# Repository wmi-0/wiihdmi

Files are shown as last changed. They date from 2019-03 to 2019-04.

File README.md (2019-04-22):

# wiihdmi
HDMI for your Wii powered by GCVideo

This PCB is based on the popular GCVideo project as well as the Shuriken V3 schematics and features HDMI output (240p, 480i, 480p) for the Wii.
Menu navigation is possible via IR-remote or Gamecube controller.  
One of the main goals for this project was to keep it as cheap as possible.
This means no flex-cable for an easier install, no replacement of analog output (RGB/Component) and most importantly a 2-layer PCB design for cheap manufacturing.

**Consider this project as a beta for now.**  
I've spent several hours testing it on my launch-model Wii, but I'd like to hear some second opinions calling it ready for general use.

## Compatibility
### main_pcb_6_layer
Confirmed to work on RVL-CPU-01 boards.  
The layout possibly fits RVL-CPU-20 as well, but this is currently untested. Won't (properly) fit RVL-CPU-30.  

### main_pcb_4_layer
The new PCB layout is designed for 4-layer Wiis (RVL-CPU-40/50/60) but it's untested as of now.

Both designs use a 2-layer PCB layout which can be manufactured on the cheap, 4/6-layer is just the number of layers used on the intended target Wii mainboard.

## Install
See [GCVideo documentation](https://github.com/ikorb/gcvideo/blob/master/HDL/gcvideo_dvi/README-Wii.md#digital-audio-and-video)

## BOM
### Main PCB
| Designator  | Component |
| --- | --- |
| U1  | XC3S200A-4VQG100C  |
| U2  | M25P40  |
| U3  | TPS74012DGKR  |
| U4  | IRM-V538/TR1  |
| SW1  | EVQ9P701P  |
| J3  | 15 pin FFC connector 0.5mm pin pitch  |
| C1, C2  | 1 uF, 0805  |
| C3  | 10 uF, 0805  |
| C4-C12  | 0.1 uF, 0805  |
| R1, R3  | 4.7K, 0805  |
| R2  | 330, 0805  |

Use 0603 components for main_pcb_4_layer.

### HDMI PCB
| Designator  | Component |
| --- | --- |
| J1  | 15 pin FFC connector 0.5mm pin pitch  |
| J2  | Mini-HDMI (Type C) socket  |
| R1  | 180, 0402  |
| R2, R3  | 10K, 0402  |
| U1-U3  | TPD4S010 DQA (optional)  |

Use 0.8mm PCB thickness for both PCBs.

## Todos and next steps
- ~~PCB for 4-layer, 65nm Wii consoles (RVL-CPU-40+)~~
- ~~Provide better install pictures showing the current version of the PCB~~
- Switch to a more common 16 pin FFC instead of 15 pin
- Possibly add half-cut vias as anchor points (the initial design already had some, but the PCB manufacturer charged extra so I removed them again)
- KiCad project cleanup

## Acknowledgements
[ikorb](https://github.com/ikorb): GCVideo project  
[Steven Taffs](http://www.retro-system.com/shuriken%20video.htm): Shuriken V3 schematic and incredibly useful M25P40 programming tool  
[citrus3000psi](https://github.com/citrus3000psi): Inspiration from GCHDMI designs

## License
This project is licensed under the GPL v3.0 License - see the LICENSE.md file for details

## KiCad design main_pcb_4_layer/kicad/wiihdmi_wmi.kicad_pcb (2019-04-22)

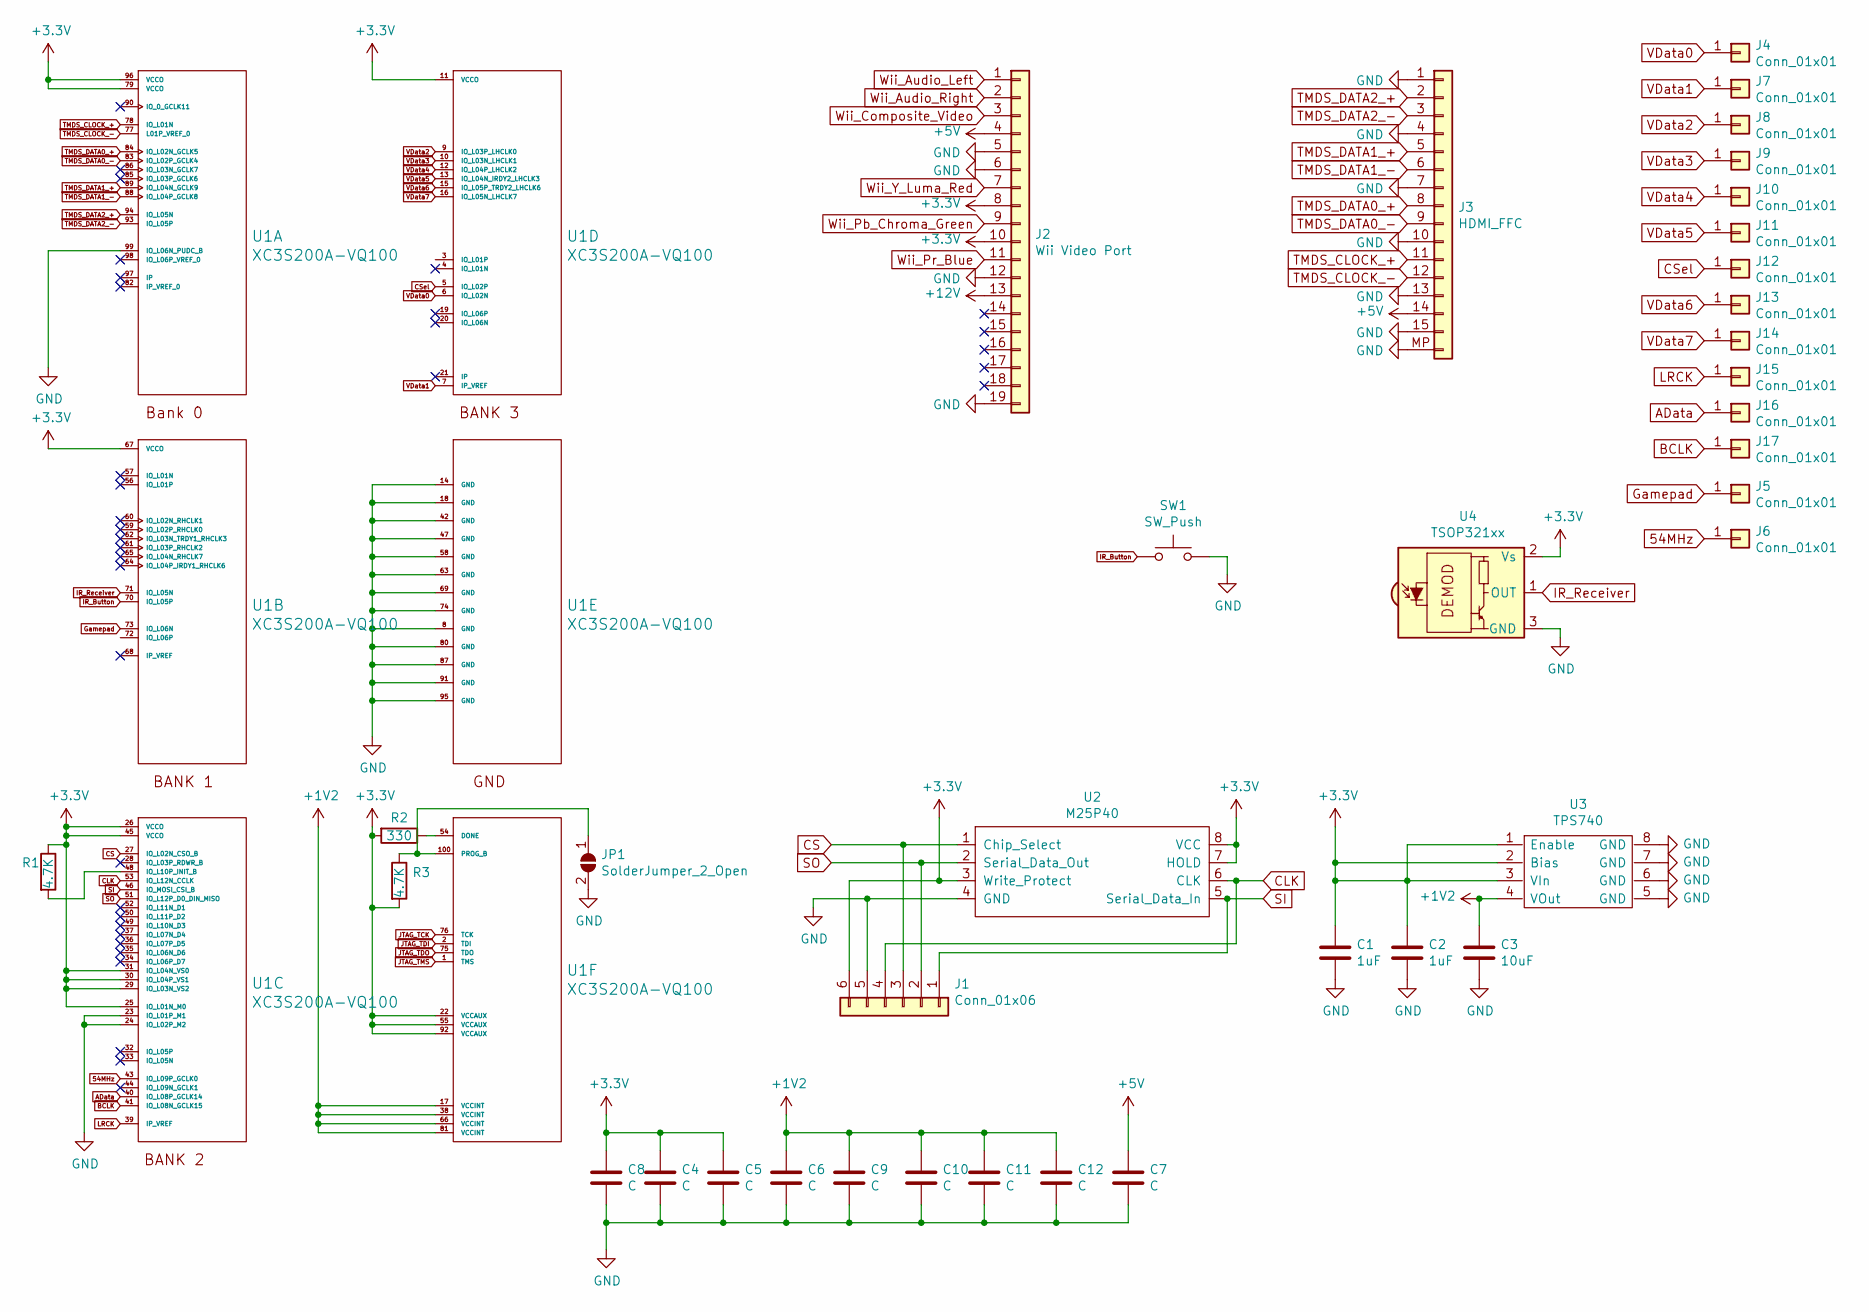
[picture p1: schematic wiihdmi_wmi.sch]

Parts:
C1, C2: 1uF; C_0805_2012Metric_Pad1.15x1.40mm_HandSolder
C3: 10uF; C_0805_2012Metric_Pad1.15x1.40mm_HandSolder
C4, C5, C6, C7, C8, C9, C10, C11, C12: C; C_0603_1608Metric_Pad1.05x0.95mm_HandSolder
J1: Conn_01x06; PinHeader_1x06_P1.27mm_Vertical_no_silk
J2: Wii Video Port; Wii AV Port
J3: HDMI_FFC; Hirose_FH12-15S-0.5SH_1x15-1MP_P0.50mm_Horizontal
J4, J5, J6, J7, J8, J9, J10, J11, J12, J13, J14, J15, J16, J17: Conn_01x01; TestPoint_Pad_1.0x1.0mm
JP1: SolderJumper_2_Open; SolderJumper-2_P1.3mm_Open_Pad1.0x1.5mm
R1, R3: 4.7K; R_0603_1608Metric_Pad1.05x0.95mm_HandSolder
R2: 330; R_0603_1608Metric_Pad1.05x0.95mm_HandSolder
SW1: SW_Push; EVQ9P701P
U1: XC3S200A-VQ100; xilinx_spartan3_virtex4_and_5-VQ100
U2: M25P40; SOIC-8_3.9x4.9mm_P1.27mm
U3: TPS740; MSOP-8_3x3mm_P0.65mm
U4: TSOP321xx; IRM-V5xx

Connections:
54MHz: J6.1, U1.43 (IO_L09P_GCLK0)
+1V2: C3.1, C6.1, C9.1, C10.1, C11.1, C12.1, U1.17 (VCCINT), U1.38 (VCCINT), U1.66 (VCCINT), U1.81 (VCCINT), U3.4 (VOut)
+3V3: C1.1, C2.1, C4.1, C5.1, C8.1, J1.6, J2.8, J2.10, R1.1, R2.2, R3.2, U1.11 (VCCO), U1.22 (VCCAUX), U1.25 (IO_L01N_M0), U1.26 (VCCO), U1.29 (IO_L03N_VS2), U1.30 (IO_L04P_VS1), U1.31 (IO_L04N_VS0), U1.45 (VCCO), U1.55 (VCCAUX), U1.67 (VCCO), U1.79 (VCCO), U1.92 (VCCAUX), U1.96 (VCCO), U2.3 (Write_Protect), U2.7 (HOLD), U2.8 (VCC), U3.1 (Enable), U3.2 (Bias), U3.3 (VIn), U4.2 (Vs)
+5V: C7.1, J2.4, J3.14
+12V: J2.13
AData: J16.1, U1.40 (IO_L08P_GCLK14)
BCLK: J17.1, U1.41 (IO_L08N_GCLK15)
CLK: J1.4, U1.53 (IO_L12N_CCLK), U2.6 (CLK)
CS: J1.3, U1.27 (IO_L02N_CSO_B), U2.1 (Chip_Select)
CSel: J12.1, U1.5 (IO_L02P)
GND: C1.2, C2.2, C3.2, C4.2, C5.2, C6.2, C7.2, C8.2, C9.2, C10.2, C11.2, C12.2, J1.5, J2.5, J2.6, J2.12, J2.19, J3.1, J3.4, J3.7, J3.10, J3.13, J3.15, J3.MP (Pin_16), JP1.2 (B), SW1.2, U1.8 (GND), U1.14 (GND), U1.18 (GND), U1.23 (IO_L01P_M1), U1.24 (IO_L02P_M2), U1.42 (GND), U1.47 (GND), U1.58 (GND), U1.63 (GND), U1.69 (GND), U1.74 (GND), U1.80 (GND), U1.87 (GND), U1.91 (GND), U1.95 (GND), U1.99 (IO_L06N_PUDC_B), U2.4 (GND), U3.5 (GND), U3.6 (GND), U3.7 (GND), U3.8 (GND), U4.3 (GND)
Gamepad: J5.1, U1.73 (IO_L06N); also elsewhere on the board
IR_Button: SW1.1, U1.70 (IO_L05P)
IR_Receiver: U1.71 (IO_L05N), U4.1 (OUT)
JTAG_TCK: U1.76 (TCK)
JTAG_TDI: U1.2 (TDI)
JTAG_TDO: U1.75 (TDO)
JTAG_TMS: U1.1 (TMS)
LRCK: J15.1, U1.39 (IP_VREF)
unnamed: JP1.1 (A), R3.1, U1.100 (PROG_B)
unnamed: R1.2, U1.48 (IO_L10P_INIT_B)
unnamed: R2.1, U1.54 (DONE)
SI: J1.1, U1.46 (IO_MOSI_CSI_B), U2.5 (Serial_Data_In)
SO: J1.2, U1.51 (IO_L12P_D0_DIN_MISO), U2.2 (Serial_Data_Out)
TMDS_CLOCK_+: J3.11, U1.78 (IO_L01N)
TMDS_CLOCK_-: J3.12, U1.77 (L01P_VREF_0)
TMDS_DATA0_+: J3.8, U1.84 (IO_L02N_GCLK5)
TMDS_DATA0_-: J3.9, U1.83 (IO_L02P_GCLK4)
TMDS_DATA1_+: J3.5, U1.89 (IO_L04N_GCLK9)
TMDS_DATA1_-: J3.6, U1.88 (IO_L04P_GCLK8)
TMDS_DATA2_+: J3.2, U1.94 (IO_L05N)
TMDS_DATA2_-: J3.3, U1.93 (IO_L05P)
VData0: J4.1, U1.6 (IO_L02N)
VData1: J7.1, U1.7 (IP_VREF)
VData2: J8.1, U1.9 (IO_L03P_LHCLK0)
VData3: J9.1, U1.10 (IO_L03N_LHCLK1)
VData4: J10.1, U1.12 (IO_L04P_LHCLK2)
VData5: J11.1, U1.13 (IO_L04N_IRDY2_LHCLK3)
VData6: J13.1, U1.15 (IO_L05P_TRDY2_LHCLK6)
VData7: J14.1, U1.16 (IO_L05N_LHCLK7)
Wii_Audio_Left: J2.1
Wii_Audio_Right: J2.2
Wii_Composite_Video: J2.3
Wii_Pb_Chroma_Green: J2.9
Wii_Pr_Blue: J2.11
Wii_Y_Luma_Red: J2.7

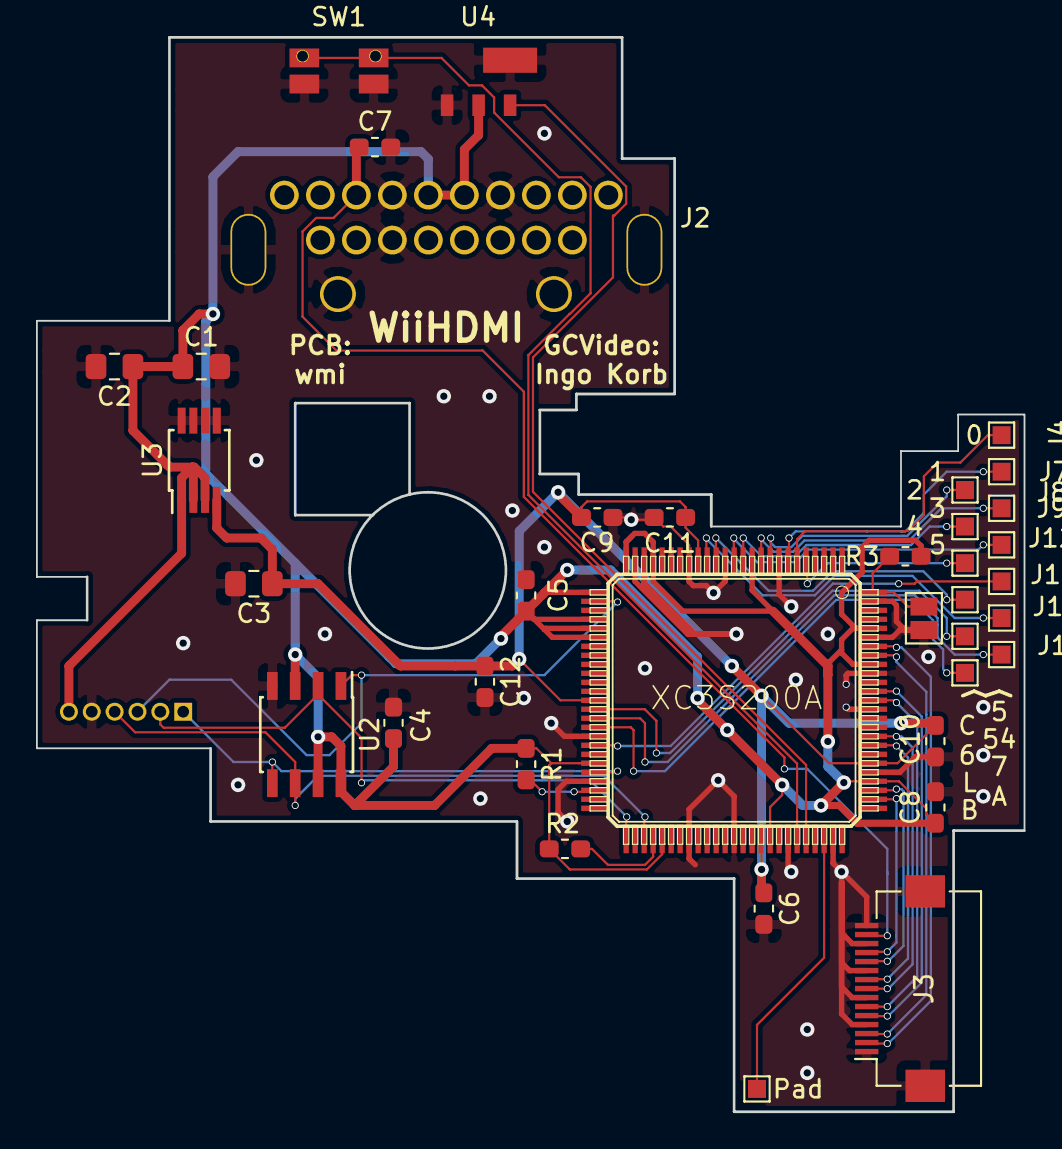
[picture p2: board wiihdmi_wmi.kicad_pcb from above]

Board: 2 copper layers, 54.9 x 59.7 mm, 38 parts (0 on the bottom side), 35 nets.

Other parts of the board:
Pad: Conn_01x01; TestPoint_Pad_1.0x1.0mm

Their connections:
Gamepad: Pad.1; also elsewhere on the board

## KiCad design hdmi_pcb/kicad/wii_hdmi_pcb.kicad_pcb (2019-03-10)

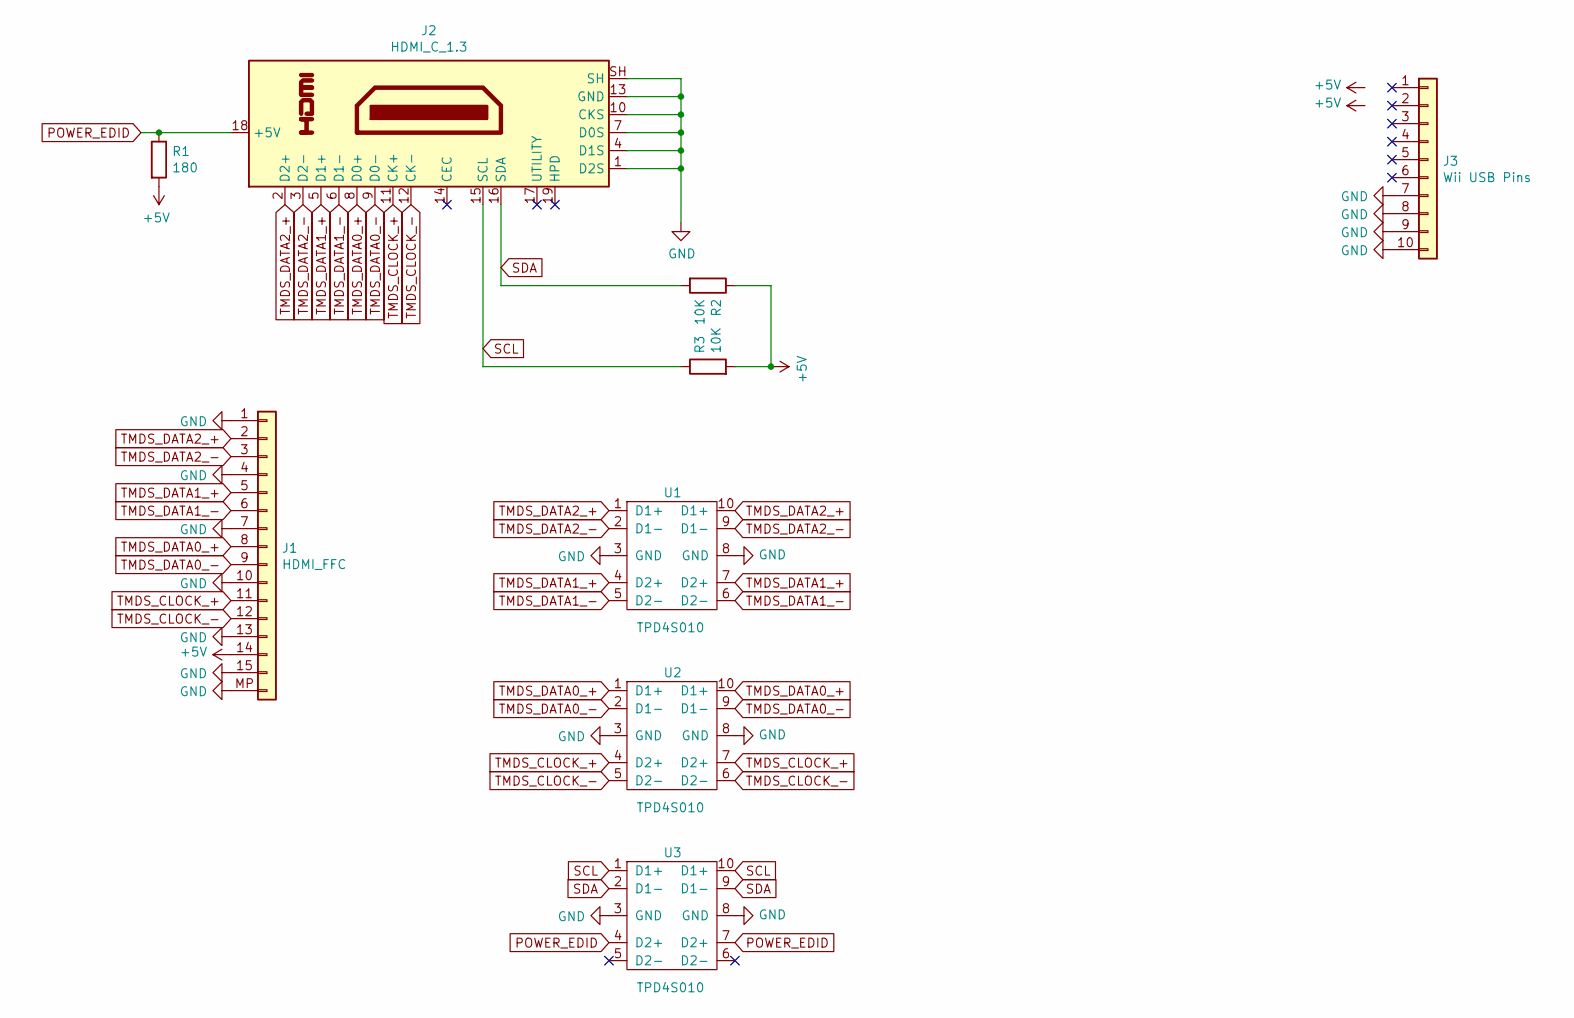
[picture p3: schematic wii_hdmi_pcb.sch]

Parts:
J1: HDMI_FFC; Hirose_FH12-15S-0.5SH_1x15-1MP_P0.50mm_Horizontal
J2: HDMI_C_1.3; HDMI Type C
J3: Wii USB Pins; Wii USB Port
R1: 180; R_0402_1005Metric
R2, R3: 10K; R_0402_1005Metric
U1, U2, U3: TPD4S010; TPD4S010 DQA

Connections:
+5V: J1.14, R1.2, R2.1, R3.2
GND: J1.1, J1.4, J1.7, J1.10, J1.13, J1.15, J1.MP (Pin_16), J2.1 (D2S), J2.4 (D1S), J2.7 (D0S), J2.10 (CKS), J2.13 (GND), J2.SH, J3.7, J3.8, J3.9, J3.10, U1.3 (GND), U1.8 (GND), U2.3 (GND), U2.8 (GND), U3.3 (GND), U3.8 (GND)
POWER_EDID: J2.18 (+5V), R1.1, U3.4 (D2+), U3.7 (D2+)
SCL: J2.15 (SCL), R3.1, U3.1 (D1+), U3.10 (D1+)
SDA: J2.16 (SDA), R2.2, U3.2 (D1-), U3.9 (D1-)
TMDS_CLOCK_+: J1.11, J2.11 (CK+), U2.4 (D2+), U2.7 (D2+)
TMDS_CLOCK_-: J1.12, J2.12 (CK-), U2.5 (D2-), U2.6 (D2-)
TMDS_DATA0_+: J1.8, J2.8 (D0+), U2.1 (D1+), U2.10 (D1+)
TMDS_DATA0_-: J1.9, J2.9 (D0-), U2.2 (D1-), U2.9 (D1-)
TMDS_DATA1_+: J1.5, J2.5 (D1+), U1.4 (D2+), U1.7 (D2+)
TMDS_DATA1_-: J1.6, J2.6 (D1-), U1.5 (D2-), U1.6 (D2-)
TMDS_DATA2_+: J1.2, J2.2 (D2+), U1.1 (D1+), U1.10 (D1+)
TMDS_DATA2_-: J1.3, J2.3 (D2-), U1.2 (D1-), U1.9 (D1-)

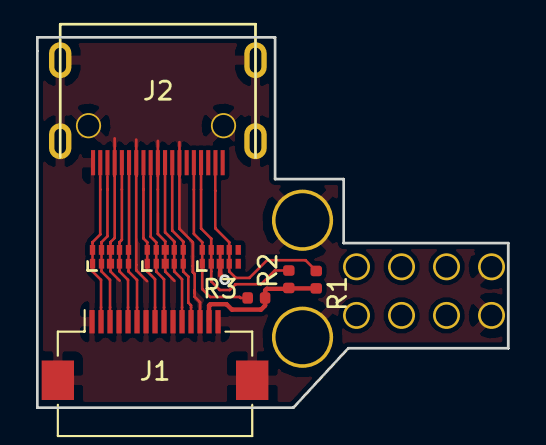
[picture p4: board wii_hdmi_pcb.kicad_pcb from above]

Board: 2 copper layers, 26.2 x 20.6 mm, 9 parts (0 on the bottom side), 13 nets.

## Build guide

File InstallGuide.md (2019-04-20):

# WiiHDMI Install Guide
Follow this to install the WiiHDMI. It involes soldering to adjacent pins on a fine-pitch IC, so it's for people that are confident with their soldering skills.  
Before you start check if your Wii is compatible with WiiHDMI. This is easily done by opening the battery cover, the revision number is printed right there on the mainboard. [Supported revisions](https://github.com/wmi-0/wiihdmi#compatibility)  
The images have been resized to reduce the bandwidth required to load this page. High-res images of each step are located in pictures\installguide if necessary.

# Step 1: Disassembly
Follow this guide to disassemble your Wii: https://www.ifixit.com/Guide/Nintendo+Wii+Motherboard+Replacement/3460  
This is more complex than a typical console teardown, take your time and pay attention to the different screw sizes. I suggest grouping them by the corresponding step number of the iFixit guide.

# Step 2: WiiHDMI install
Make sure that both PCBs are aligned straight and are placed as close as possible to the Wii mainboard. Use solder wick to remove some of the solder on the GND pins if necessary.  
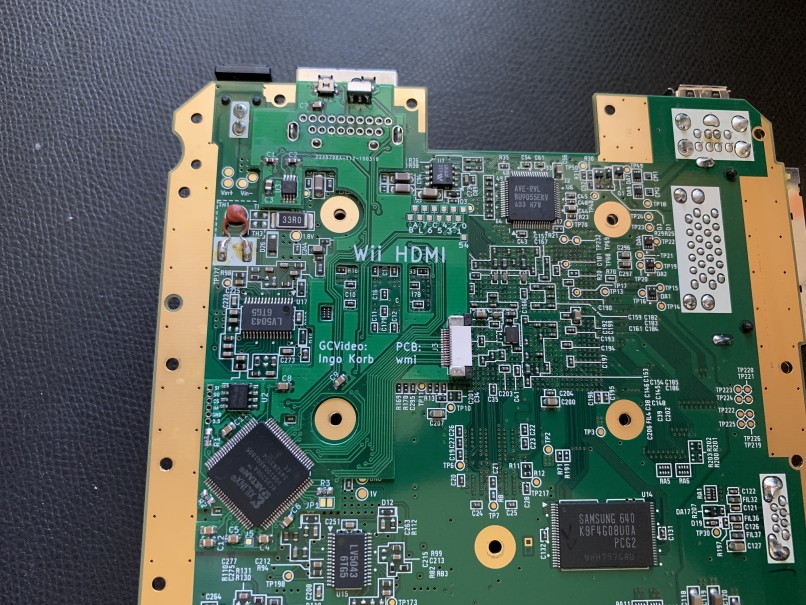
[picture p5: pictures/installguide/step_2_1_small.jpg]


Solder the Main PCB and HDMI PCB to the board.  
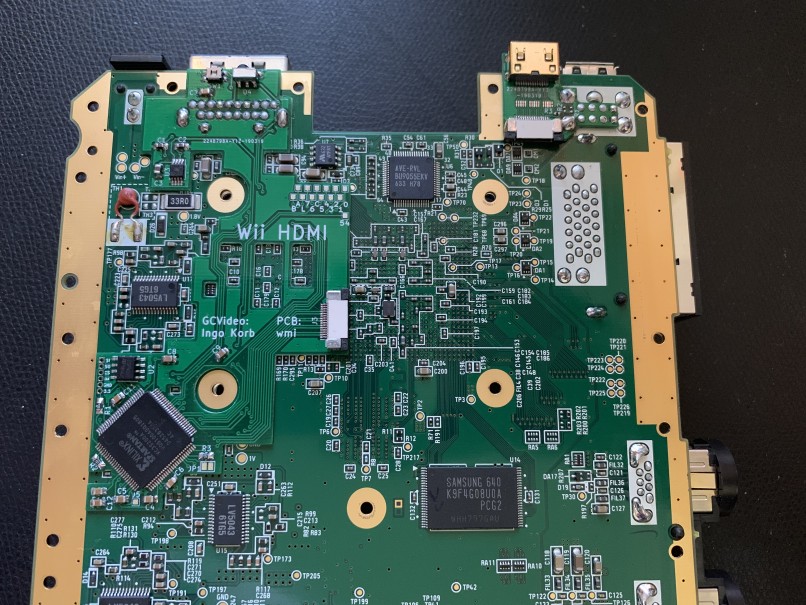
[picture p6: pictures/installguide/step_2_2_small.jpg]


Connect the pads to the AVE-RVL.  
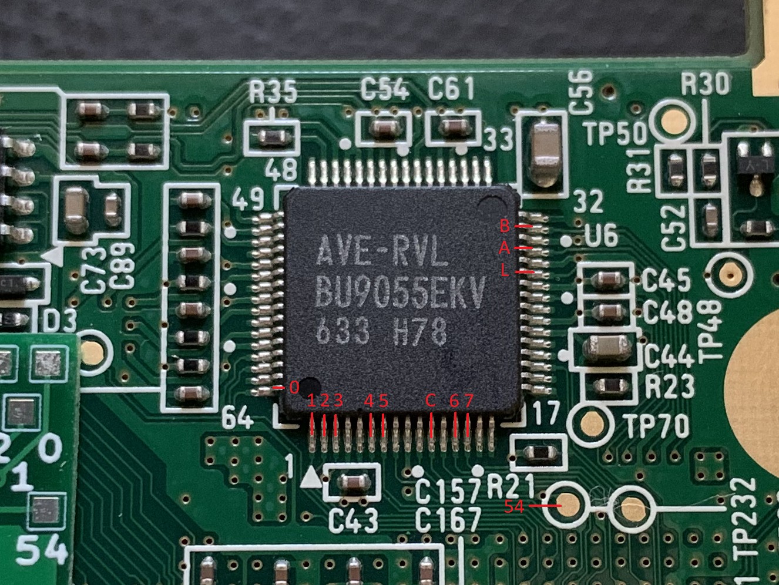
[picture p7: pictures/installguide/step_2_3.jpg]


When finished it should look something like this.  
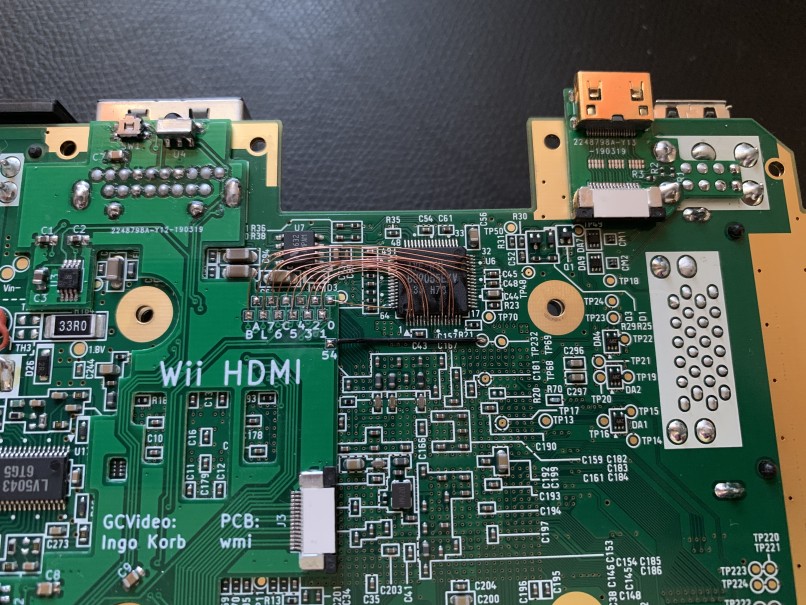
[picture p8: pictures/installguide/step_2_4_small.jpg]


Now we just need to connect the solder pad for the gamepad to TP27, which is Gamecube controller port 1.  
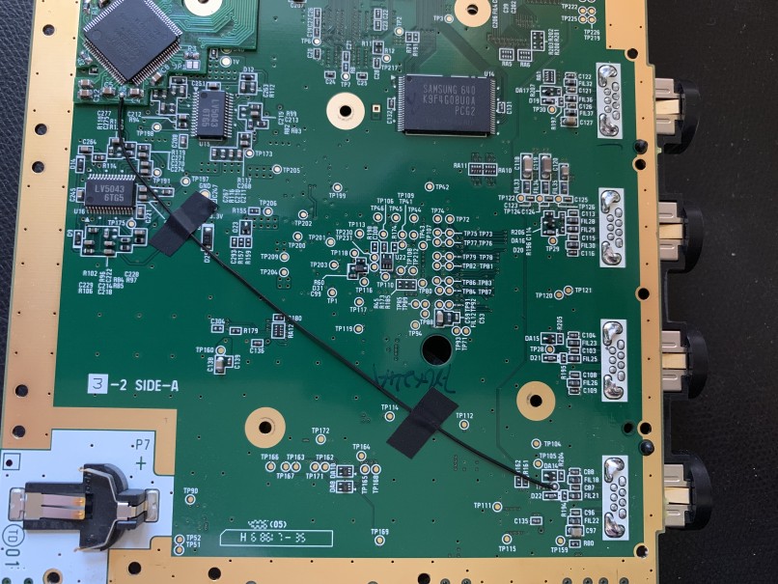
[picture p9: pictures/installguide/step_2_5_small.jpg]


And finally insert the ribbon cable and fold appropriately. Don't risk breaking the FFC by folding it too tight, there's plenty of space between the mainboard and shielding.  
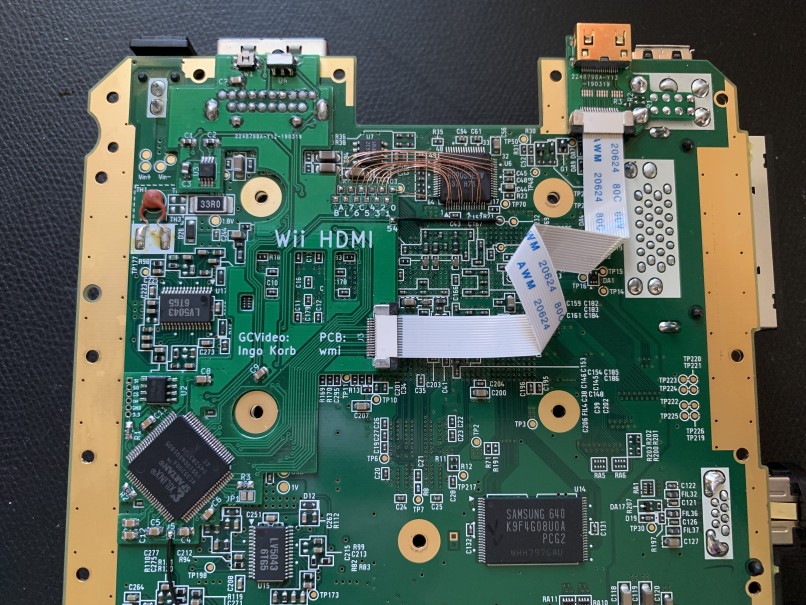
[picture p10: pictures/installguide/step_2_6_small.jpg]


Now it's a good idea to test if the installation was successful. Place the top RF shield back on, connect the drive and place a piece of plastic or paper under the drive to avoid shorting something.
Connect power and the Mini-HDMI cable. If everything went well you should be greeted by the Wii menu.

# Step 3: Modifications
The bottom RF shield needs to be modified to allow for some space for the added boards. Use some pliers to wiggle or cut off the marked sections.  
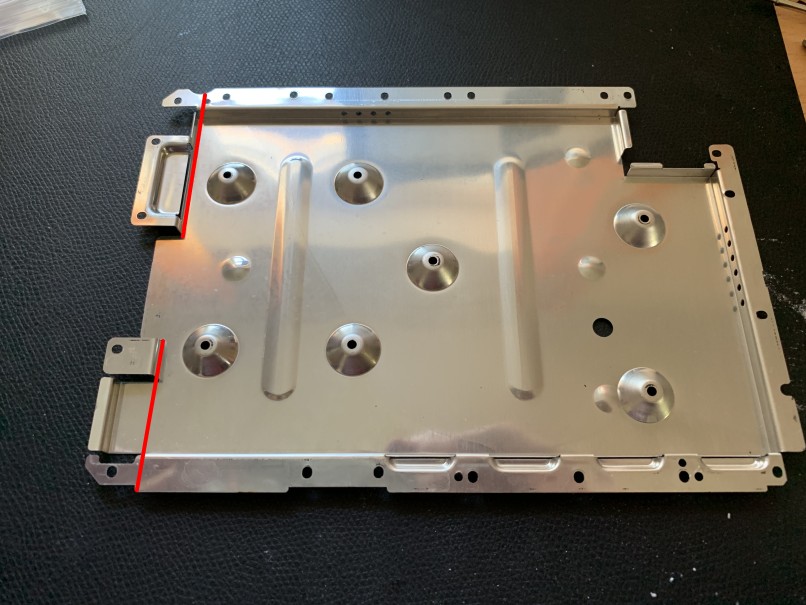
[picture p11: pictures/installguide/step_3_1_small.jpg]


Like so.  
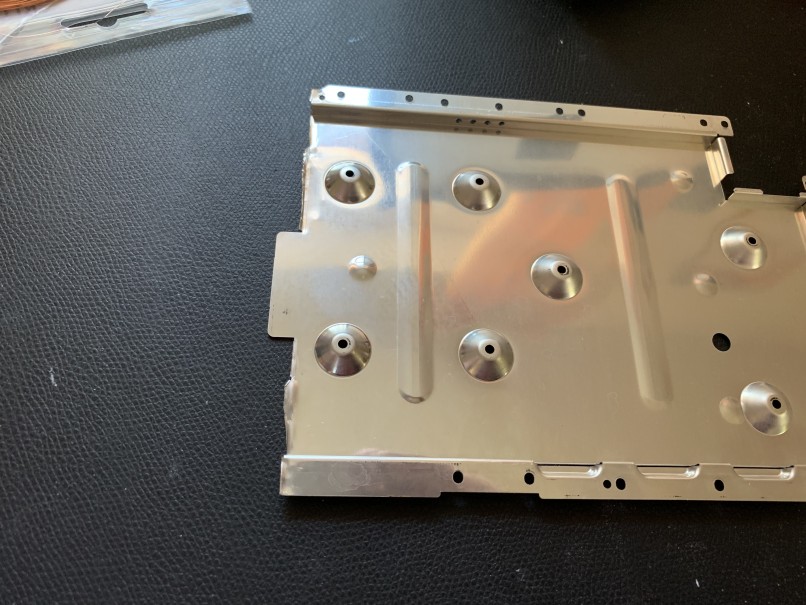
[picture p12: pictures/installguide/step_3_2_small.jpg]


Now we need to modify the bottom plastic shell to fit the Mini-HDMI connector. Mark the edges of the connector with a pen.  
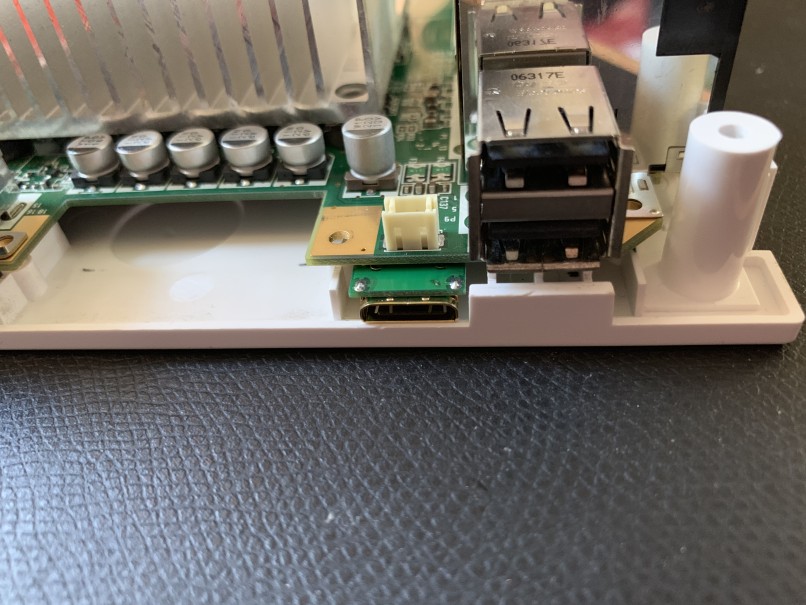
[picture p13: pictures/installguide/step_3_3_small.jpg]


And use a file to create a cutout to fit the connector.  
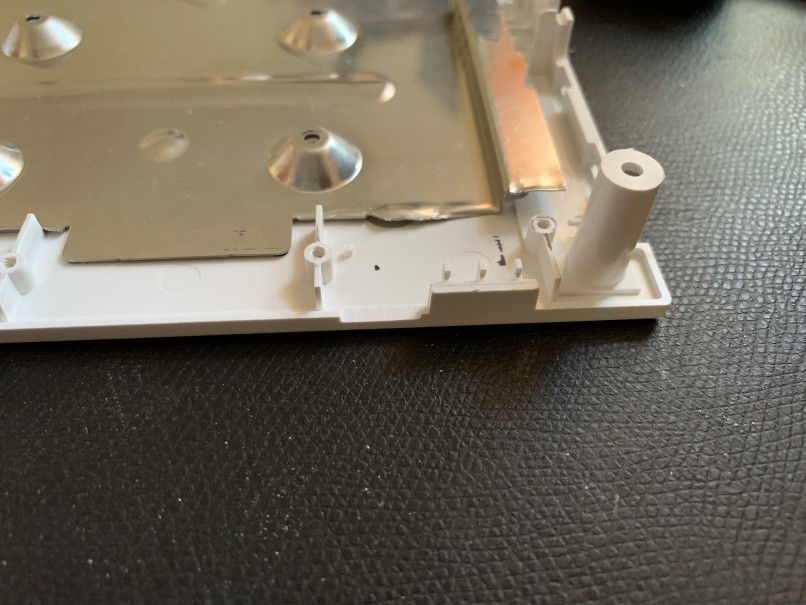
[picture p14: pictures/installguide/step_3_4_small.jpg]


On the other side mark the position of the Switch and the IR sensor. Then drill a small hole for each at the approximate position.  
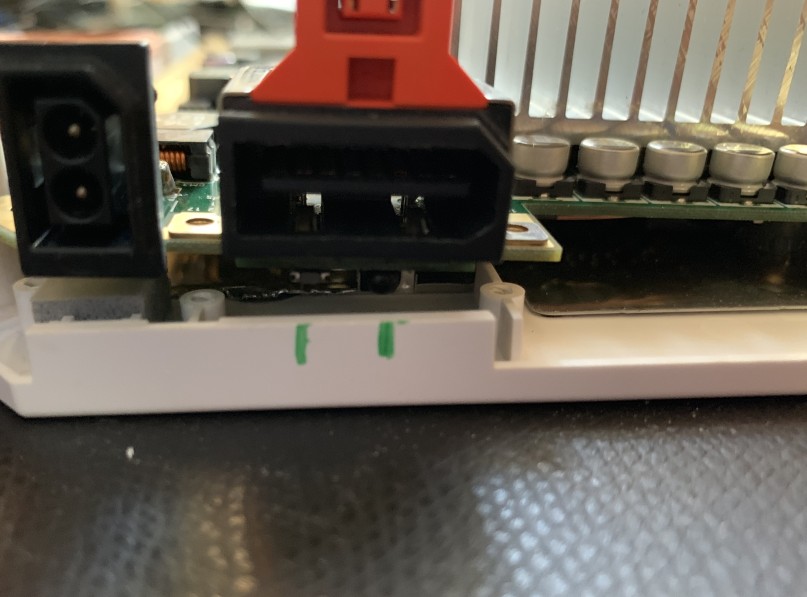
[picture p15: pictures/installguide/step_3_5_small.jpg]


Also cut of a part of the sponge the power pins press against for it to clear the WiiHDMI PCB.  
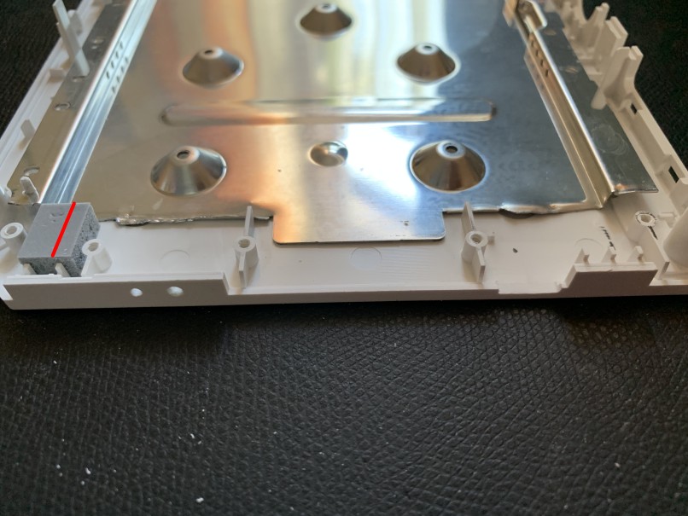
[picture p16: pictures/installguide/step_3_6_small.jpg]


The upper part of the case needs to be modified as well. Put it on top, mark the position of the connector and file away.  
Depending on the placement of the HDMI PCB it's possible that the inner wall of the case needs to be made a bit thinner for it to clear the PCB and allow the case to close properly.  
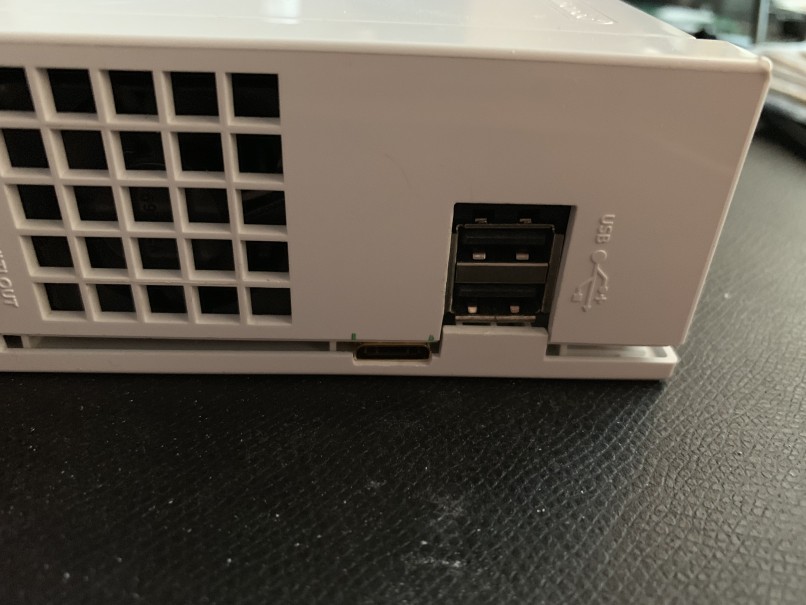
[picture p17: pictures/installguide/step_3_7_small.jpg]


After all the work it should look something like this.  
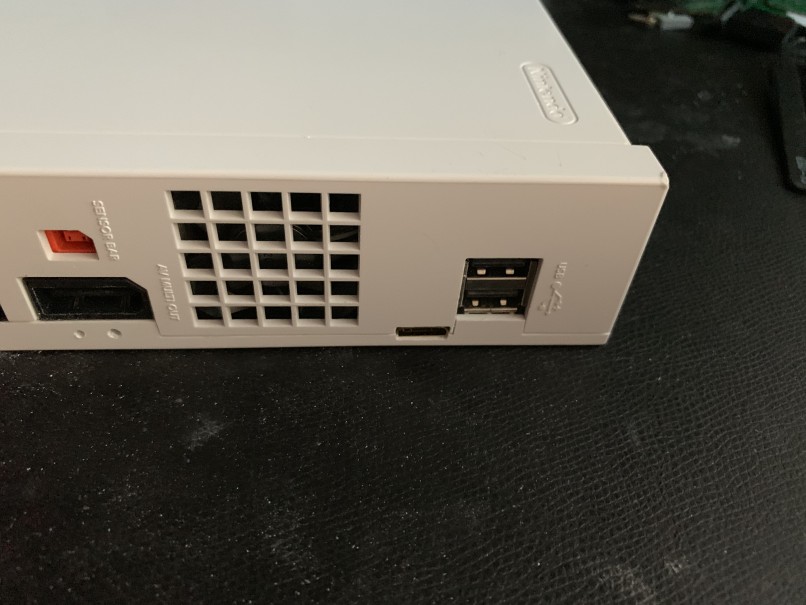
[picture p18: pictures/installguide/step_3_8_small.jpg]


# Step 4: Reassembly
Follow the iFixit guide in reverse order. If you've kept track of the screws it should be pretty easy this time.

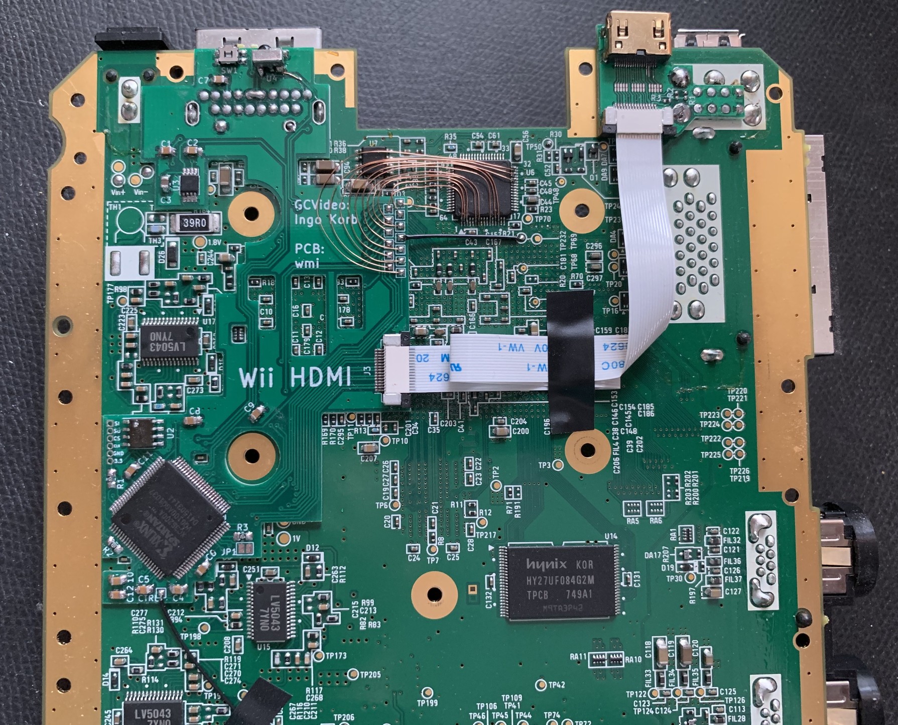
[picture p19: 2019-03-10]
pictures/install.jpg

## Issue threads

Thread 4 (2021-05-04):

No signal

TyMiles2012, 2021-05-04:
Hi!  I recently put this together for my RVL-CPU-01, but I'm not getting any signal.  Continuity checks out, and I flashed the Shuriken v3 Wii version of GCVideo 3.0e using a CH341A programmer, but I'm not getting any signal.  I tried checking continuity again, reflowing the FPGA and 25P40 and the holes that attach to the console motherboard, even rebuilt the HDMI PCB.  Nothing.  Is there anything else I could check?

wmi-0, 2021-05-09:
Hi, did you reconnect the drive and all other PCBs (Wifi, Bluetooth) before testing)? They are required for the Wii to boot.
Another easy thing to check is if U3 (TPS74012DGKR) outputs 1,2V. I've had a few bad ones in the past.

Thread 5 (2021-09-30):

Recommended substitute for M25P40?

WillD7545, 2021-09-30:
Going through Digikey for the parts in the BOM. The M25P40 seems to be an obsolete part at this point in time and the only in-stock option is from a market place seller in a VDFPN package. The GC Dual has an MX25L4006EM2I-12G in it's schematic, but that one is also hard to find. Would a MX25V4006EM1I-13G be an acceptable substitute?

jpaglier, 2022-01-19:
I've used MX25V4006EM1I-13G without issue.

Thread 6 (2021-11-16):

Substitute for TPD4S010 DQA

bahamutfan64, 2021-11-16:
Would the SP3012-04UTG diode, which is used in Arthrimus' Wii HDMI implementation, be an equivalent replacement here?

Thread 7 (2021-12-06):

Capacitor and Resistor ratings

Skuzee, 2021-12-06:
Hello!

Sorry to bother you for a bit this, but I was wondering if there were any significant requirements when choosing the capacitors and resistors. What voltage rating (I suspect it's no more than 5v?, does accuracy or capacitor type matter? How many watts for these resistors? 1/16th?

Thanks so much! 💛

bahamutfan64, 2022-01-10:
For the caps, 16v and higher should work great, 10%.

for the resistors, 1/10 Watt is good.

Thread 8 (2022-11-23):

Recommended parts list?

opensourcenebula, 2022-11-23:
I've been scouring the internet for a mod that will work on my RVL-CPU-01 and RVL-CPU-20 Wiis, and this is the only thing I've found that will work at all- And I don't want to start collecting Wiis or spring for a WiiU. I'd rather just use what I have.

That said, do you have a parts list or at least general "here's what you need, go find specifics yourself" list? I'm sure I'd be able to figure it out with enough staring and googling, but I know asking is faster and leaves less room for me to screw up- I'm terrible at understanding PCBs and the components that go on them, just good at soldering them. I tried seeing if you'd included one with everything else but couldn't find one.

This is probably a very simple issue, but anything related to the creation of electronics that isn't "physical assembly" escapes me.

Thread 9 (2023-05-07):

👍

L10N37, 2023-05-07:
Non-issue .. just curious.
These mods have gained popularity very recently and yours is 4 years old. Wondering why this was never put into production and so forth?

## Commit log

2019-03-10 Added project
    [wii_hdmi_pcb-B.Cu.gbl, wii_hdmi_pcb-B.Mask.gbs, wii_hdmi_pcb-B.Paste.gbp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]
2019-04-20 New pictures of current PCB rev
2019-04-22 Renamed main_pcb to main_pcb_6_layer
    [wiihdmi_wmi-B.Cu.gbl, wiihdmi_wmi-B.Mask.gbs, wiihdmi_wmi-B.Paste.gbp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]
2019-04-22 New PCB variant for 4-layer Wiis
    [wiihdmi_wmi-B.Cu.gbl, wiihdmi_wmi-B.Mask.gbs, wiihdmi_wmi-B.Paste.gbp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]
